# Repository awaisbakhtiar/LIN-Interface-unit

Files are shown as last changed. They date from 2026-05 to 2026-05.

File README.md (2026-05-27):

Developed a LIN Interface Unit for camper van applications to sniff and monitor parameters on the LIN-Bus network. Designed the system to comply with ISO 7637 automotive transient protection standards, incorporating analog and digital isolation, overvoltage and undervoltage protection, and transient suppression circuitry for reliable operation in automotive environments. Integrated an ESP32 for wireless communication with a mobile application over Wi-Fi.

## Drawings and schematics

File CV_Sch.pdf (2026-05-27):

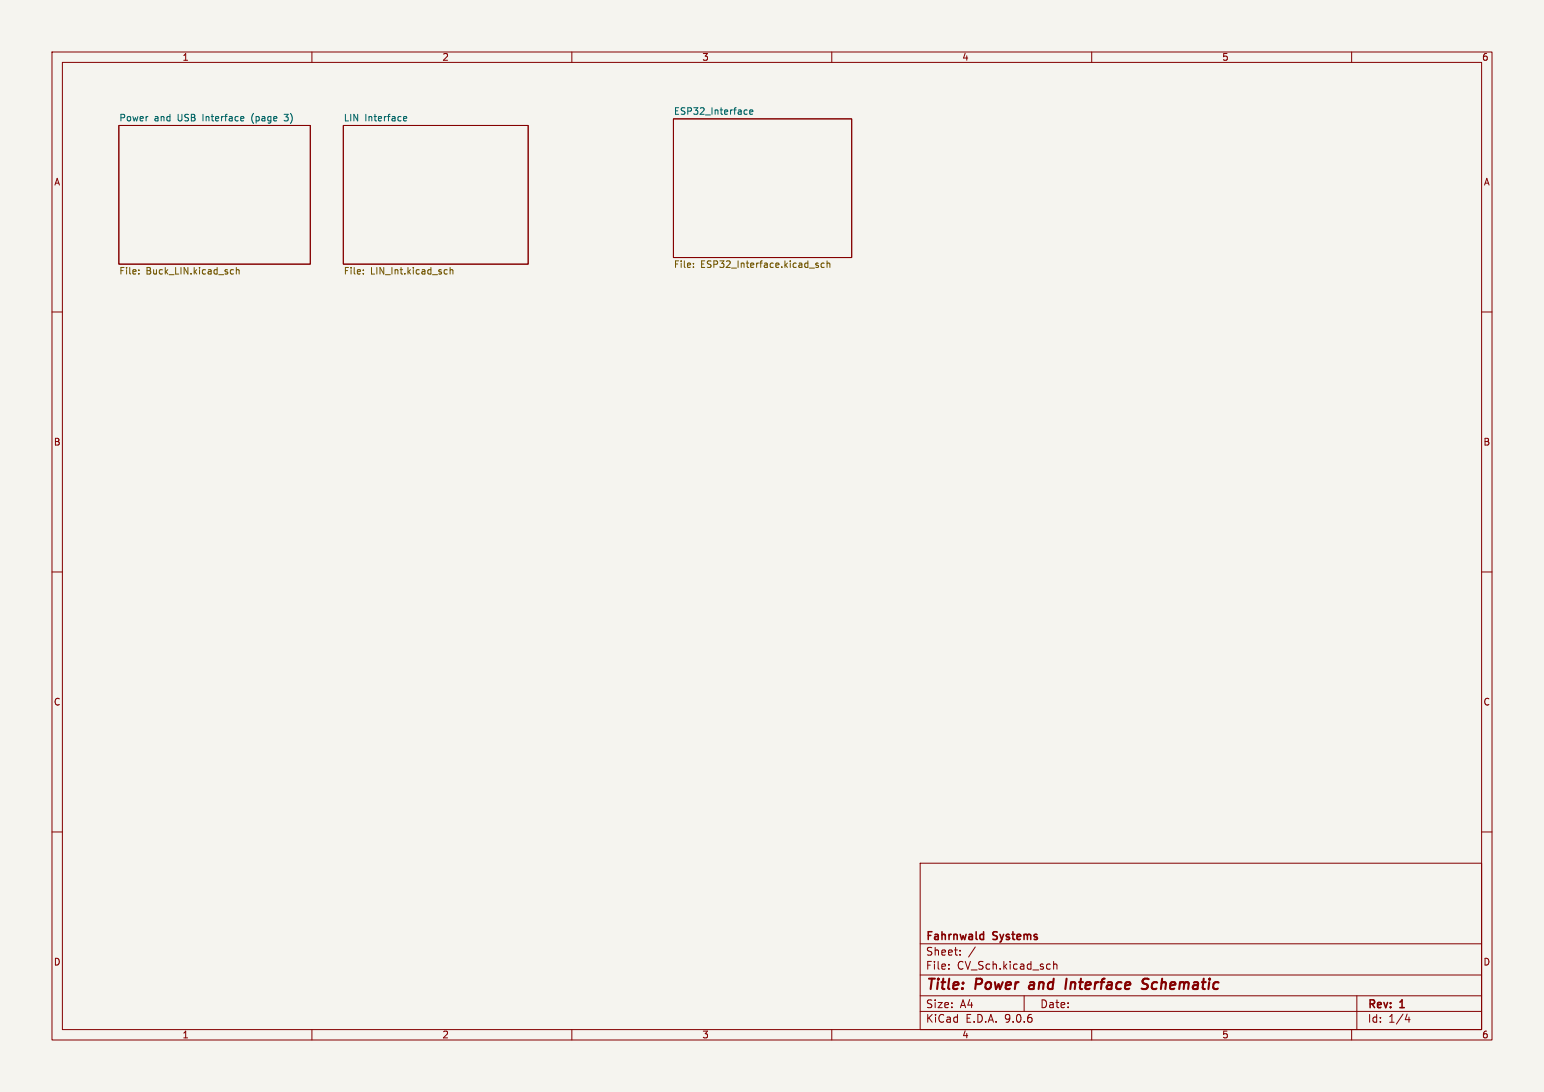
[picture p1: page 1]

Id: 1/4 Title: Power and Interface Schematic

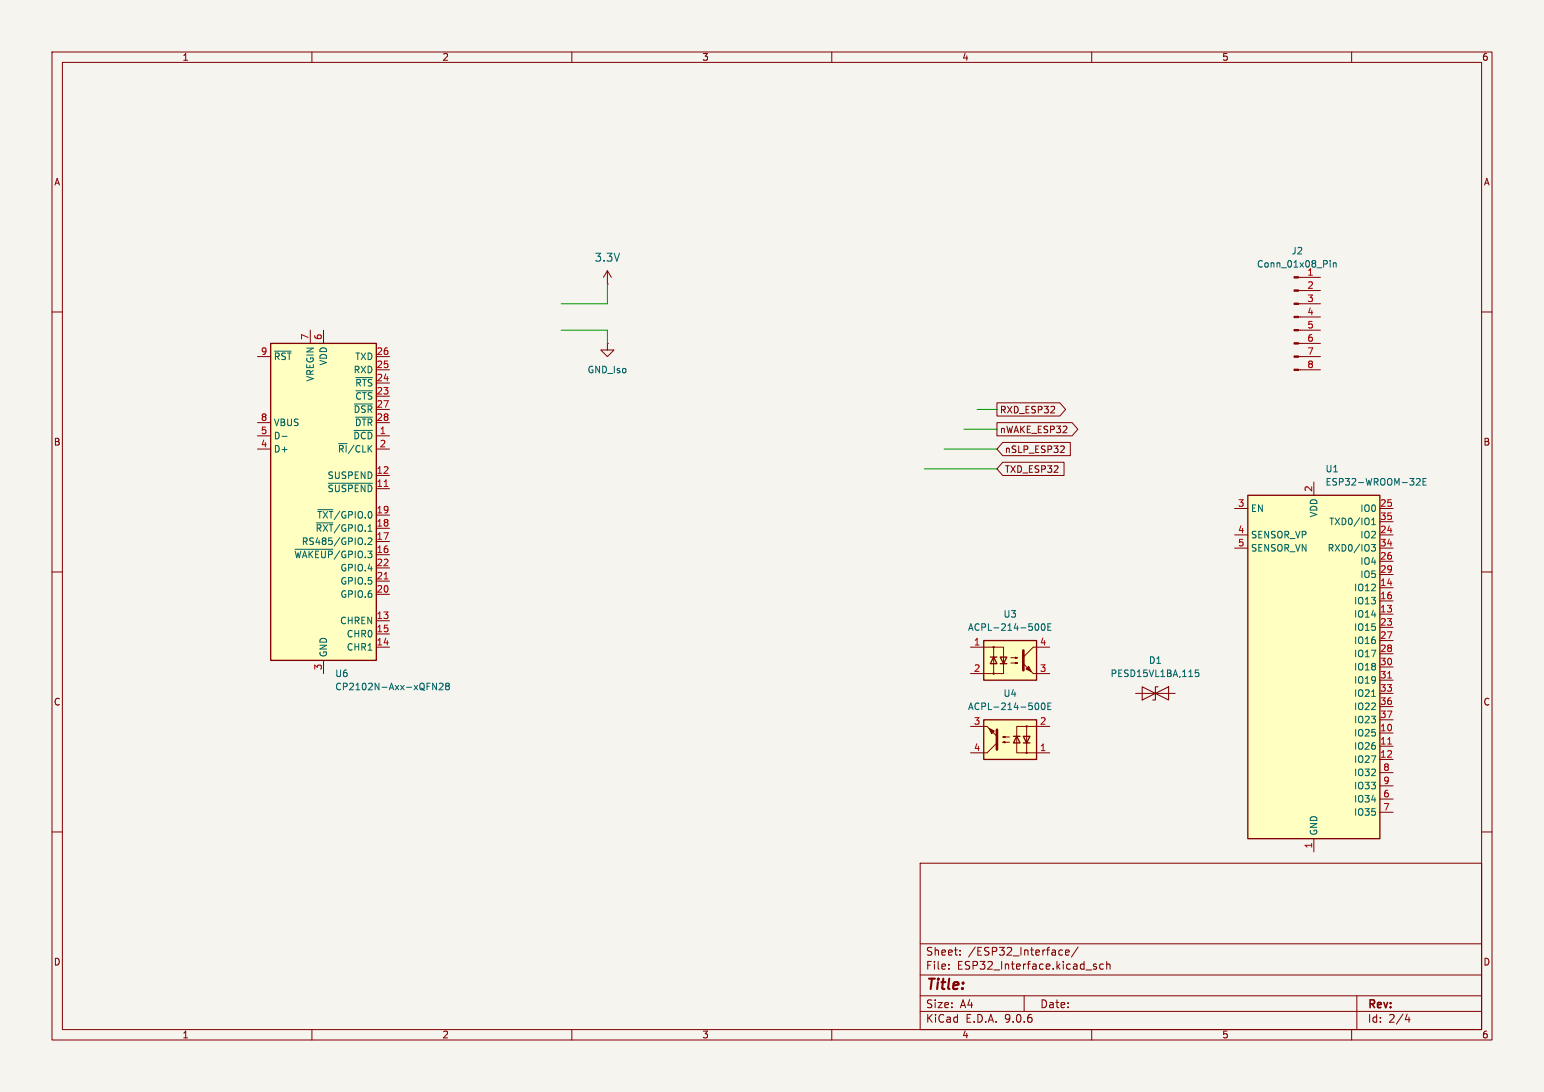
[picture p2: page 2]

Id: 2/4 Title: File: ESP32_Interface.kicad_sch Sheet: /ESP32_Interface/

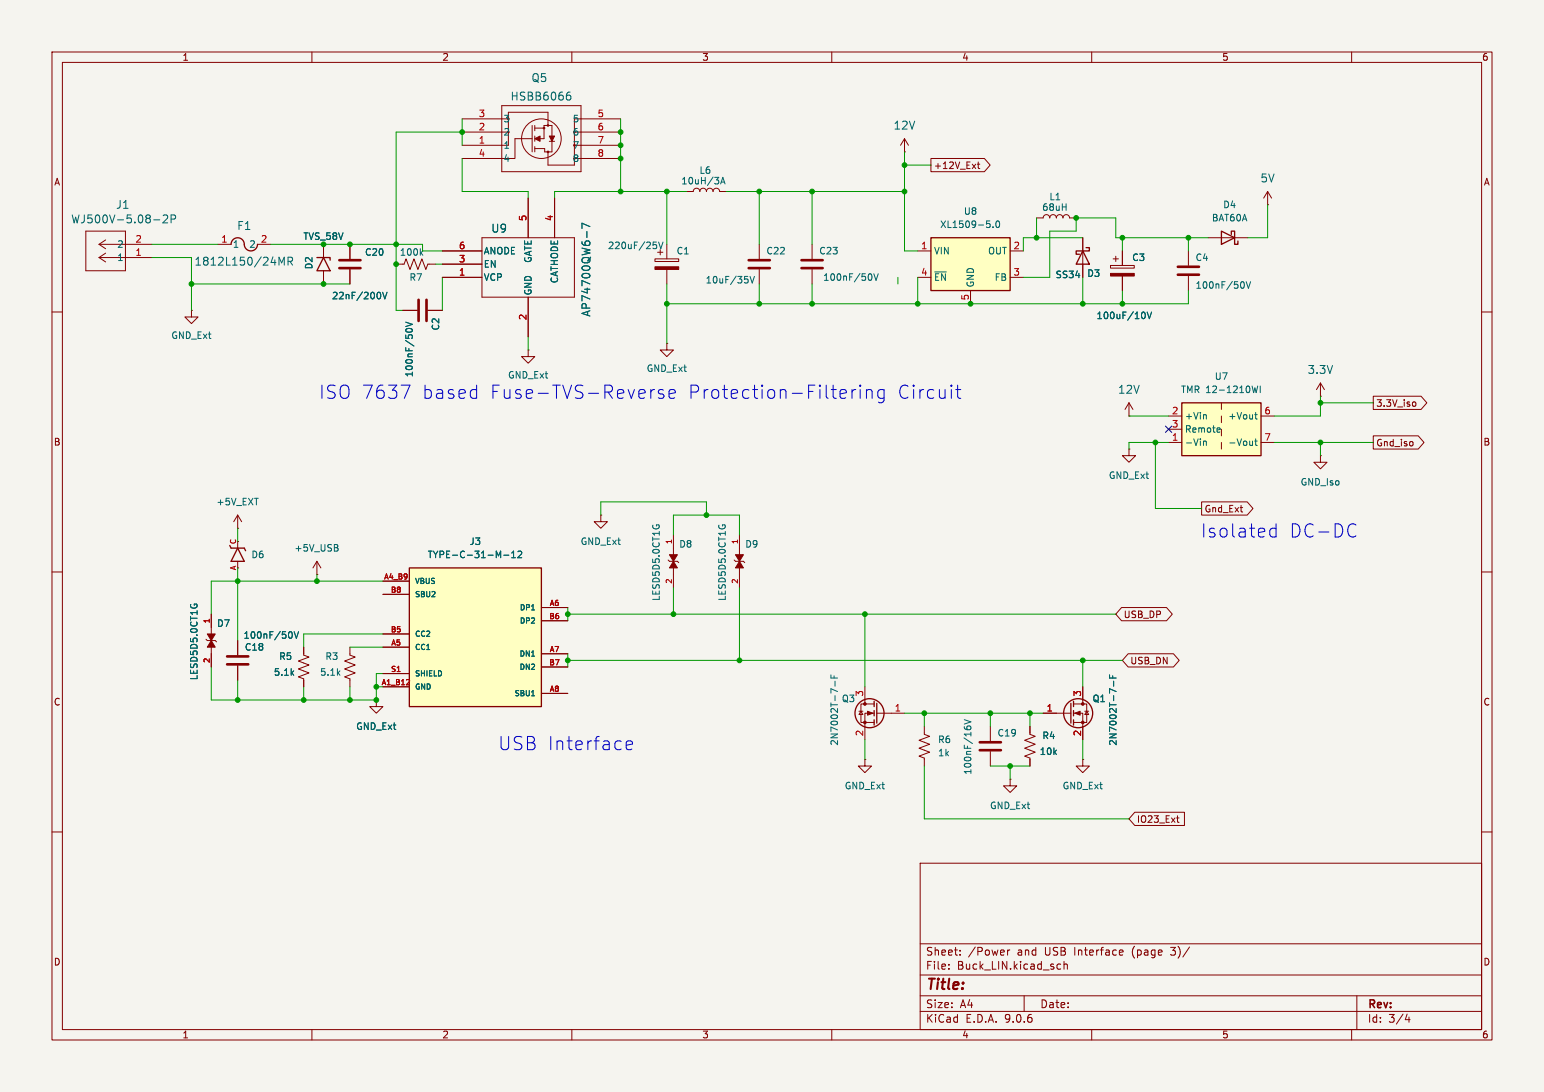
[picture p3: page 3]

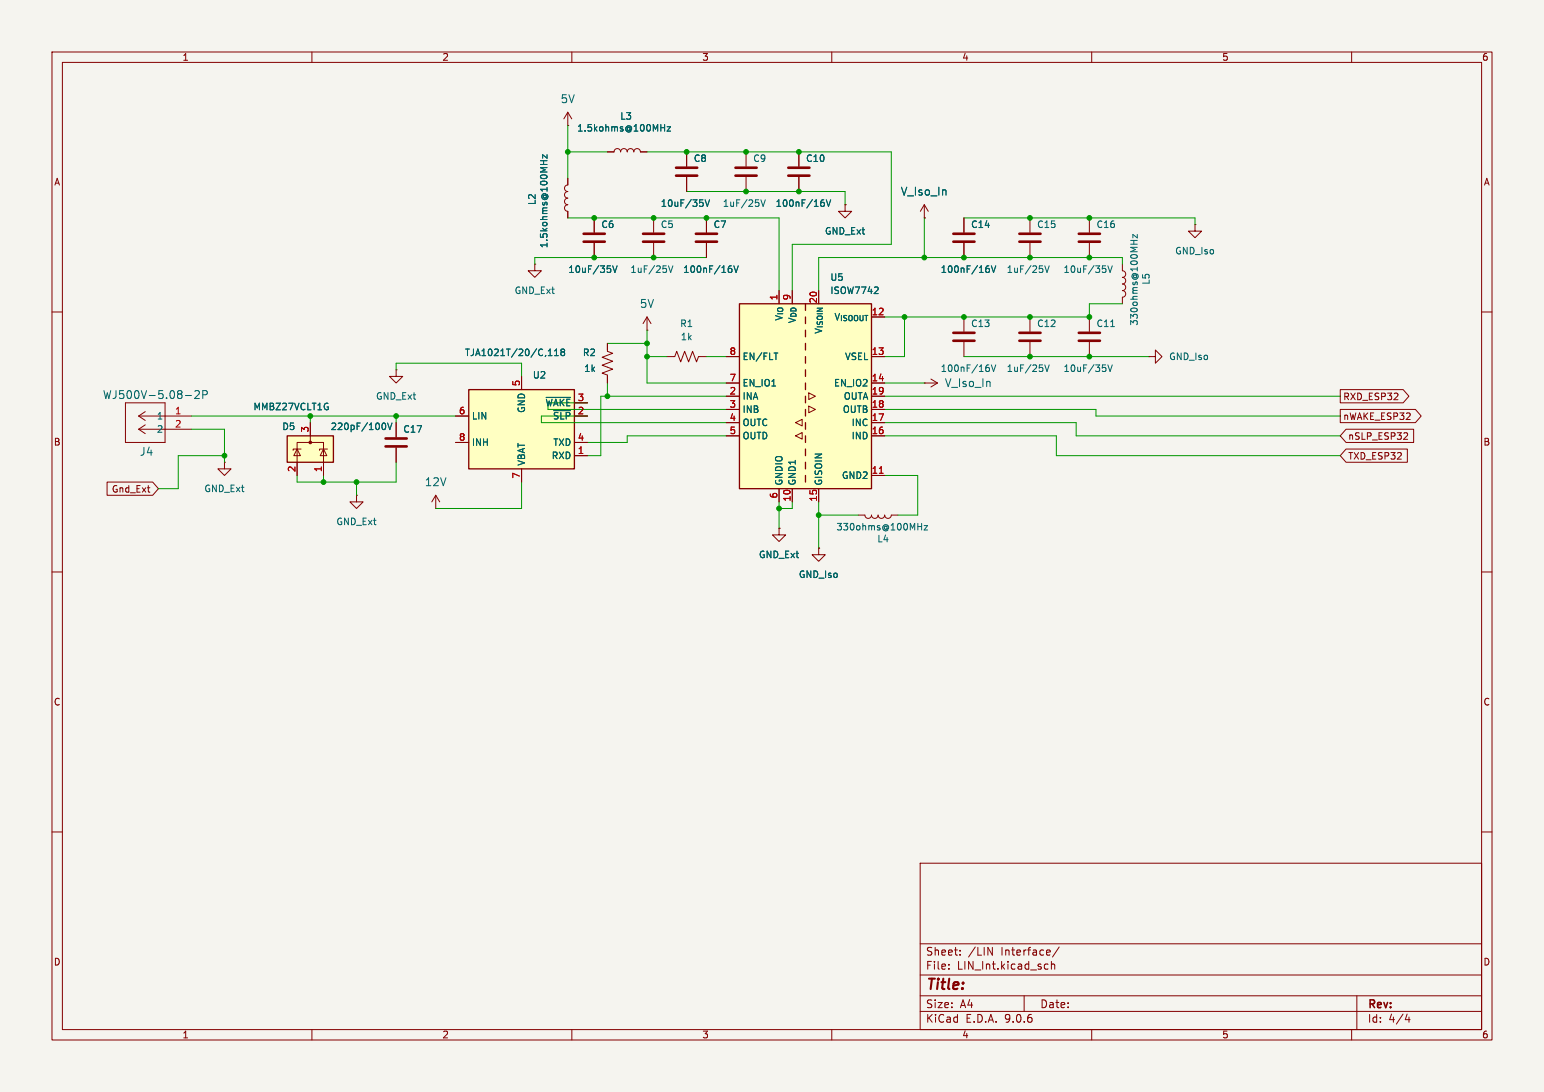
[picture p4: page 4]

1 C17 220pF/100V U2 TJA1021T/20/C,118 RXD 1 TXD 4 ~{SLP}2 ~{WAKE}3 VBAT

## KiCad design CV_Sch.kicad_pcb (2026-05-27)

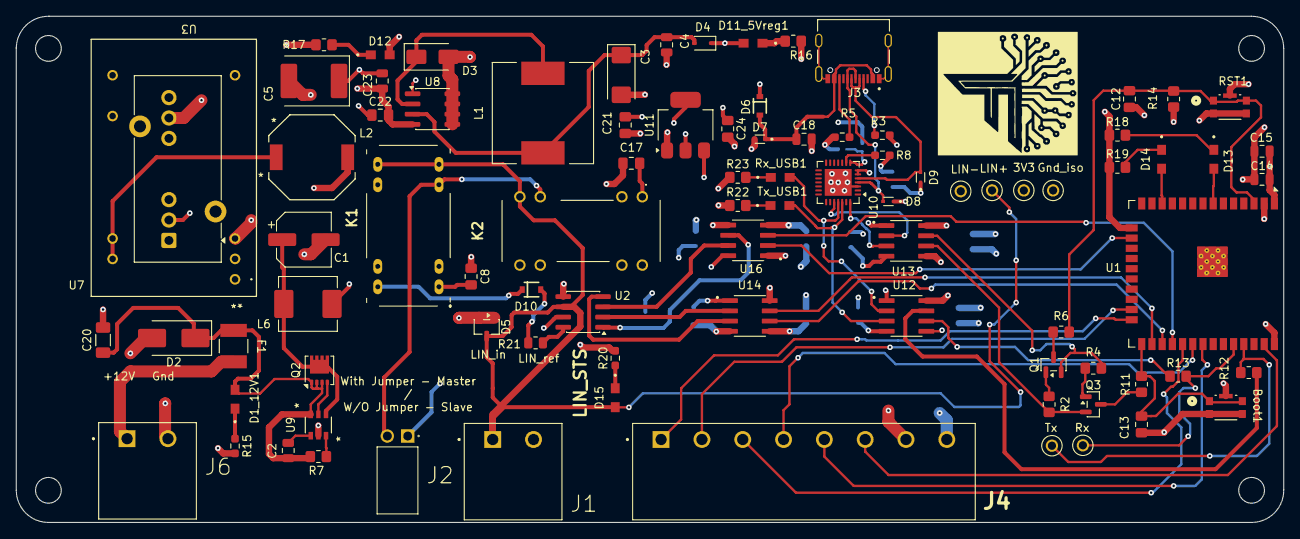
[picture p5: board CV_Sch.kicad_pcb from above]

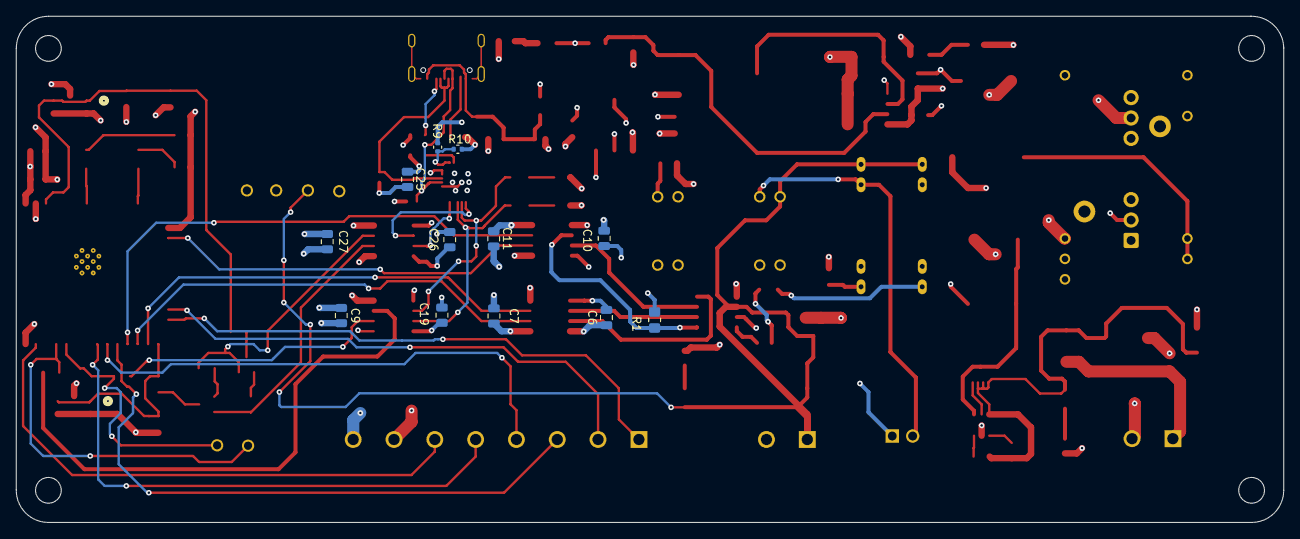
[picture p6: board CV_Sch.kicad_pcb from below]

Board: 4 copper layers, 157.8 x 63.0 mm, 104 parts (12 on the bottom side), 69 nets.

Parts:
Boot1: KMR223G LFG; KMR2_G_CNK_Y78B22310FP
C1: 220uF/25V; CP_Elec_6.3x7.7
C2, C4, C6, C7, C9, C10, C11, C14, C18, C19, C23, C26, C27: 100nF/50V; C_0805_2012Metric
C3: 100uF/10V; CP_EIA-6032-28_Kemet-C
C5: 100uF/25V; CP_EIA-7360-38_Kemet-E
C8: 1nF/50V; C_0805_2012Metric_Pad1.18x1.45mm_HandSolder
C12, C13, C21, C22, C24: 10uF/35V; C_0805_2012Metric_Pad1.18x1.45mm_HandSolder
C15: 22uF/16V; C_0805_2012Metric
C17: 220pF/100V; C_0805_2012Metric_Pad1.18x1.45mm_HandSolder
C20: 22nF/200V; C_1206_3216Metric_Pad1.33x1.80mm_HandSolder
C25: 4.7uF/16V; C_0805_2012Metric
D1_12V1, D11_5Vreg1, D12: APT2012SURCK; LED_APT2012SURCK
D2: TVS_58V; D_SMB_Handsoldering
D3: SS34; D_SMA
D4: BAT60A; D_SOD-323
D5: MMBZ27VCLT1G; SOT-23-3
D6: BAT20JFILM; SOD-323
D7, D8, D9: LESD5D5.0CT1G; TVS_LESD5D5.0CT1G
D10: MBR0520LT1G; SOD-323
D13, D14, D15: APT2012ZGC; LED_APT2012SURCK
F1: 1812L150/24MR; FUSE_1812L150&slash_24_LTF
H1, H2, H3, H4: MountingHole; MountingHole_3.2mm_M3
J1, J6: 1757242; PHOENIX_1757242
J2: M20-9750242; M20-97502XX
J3: TYPE-C-31-M-12; HRO_TYPE-C-31-M-12
J4: 1757307; PHOENIX_1757307
K1: HE722A1210
K2: 8L41-12-001
L1: 68uH; L_12x12mm_H6mm
L2: 12uH; IND_CDRH104_SUM
L6: 10uH/3A; L_TechFuse_SL0624
Q1, Q3: SS8050; SOT-23
Q2: DMT6008LFG; Diodes_PowerDI3333-8
R1, R2, R4, R14: 10k; R_0805_2012Metric_Pad1.20x1.40mm_HandSolder
R3, R5: 5.1k; R_0603_1608Metric_Pad0.98x0.95mm_HandSolder
R6, R11, R12, R13: 22R; R_0805_2012Metric_Pad1.20x1.40mm_HandSolder
R7: 100k; R_0805_2012Metric_Pad1.20x1.40mm_HandSolder
R8, R15, R20: 1k; R_0603_1608Metric_Pad0.98x0.95mm_HandSolder
R9: 22.1k; R_0402_1005Metric
R10: 47.5k; R_0402_1005Metric
R16: 330R; R_0805_2012Metric_Pad1.20x1.40mm_HandSolder
R17, R18, R19, R22, R23: 120R; R_0805_2012Metric_Pad1.20x1.40mm_HandSolder
R21: 1k; R_0805_2012Metric
RST1: KMR223G LFG; KMR2_G_CNK_Y78B22310FP
Rx_USB1: APT2012SURCK; LED_APT2012SURCK
TP1: RH-5000; TestPoint_RH-5001(black)
TP2, TP4: RH-5001; TestPoint_RH-5001(black)
TP3: RH-5004; TestPoint_RH-5001(black)
TP5: RH-5117; TestPoint_RH-5001(black)
TP6: RH-5116; TestPoint_RH-5001(black)
Tx_USB1: APT2012SURCK; LED_APT2012SURCK
U1: ESP32-WROOM-32E; ESP32-WROOM-32D
U2: TJA1021T/20/C,118; SOIC-8_3.9x4.9mm_P1.27mm
U3: JCG1212S3V3; RLA_JCG12_JCG15_SINGLE_XPR
U7: TMR 12-1210WI; Converter_DCDC_TRACO_TMR10-24xxWIR_48xxWIR_72xxWIR_THT
U8: XL1509-5.0; SOIC-8_3.9x4.9mm_P1.27mm
U9: AP74700QW6-7; SOT26_DIO
U10: CP2102N-A02-GQFN28R; QFN-28-1EP_5x5mm_P0.5mm_EP3.35x3.35mm
U11: AMS1117-3.3; SOT-223-3_TabPin2
U12: ISO7421DR; SOIC127P599X175-8N
U13, U14, U16: ISO7420FED; SOIC127P599X175-8N

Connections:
3.3V_iso: C7.2, C9.2, C11.2, C14.1, C15.2, C27.2, D12.2, J4.07, R14.1, TP1.TP, U1.2 (VDD), U3.14 (+VOUT), U7.6 (+Vout), U12.8 (VCC2), U13.8 (VCC2), U14.8 (VCC2), U16.1 (VCC1)
5V_Ext: C6.1, C10.1, C21.1, D4.1 (K), D6.C, D11_5Vreg1.2, R1.2, R9.2, U11.3 (VI), U14.1 (VCC1), U16.8 (VCC2)
+3.3V_EXT: C19.2, C24.1, C25.1, C26.1, R8.2, U10.6 (VDD), U10.7 (VREGIN), U11.2 (VO), U12.1 (VCC1), U13.1 (VCC1)
+5V_USB: C18.1, D6.A, D7.1, J3.A4_B9 (VBUS), J3.B4_A9 (VBUS)
+12V_Ext: C5.1, C22.1, C23.1, J2.1, L2.2, L6.2, U2.7 (VBAT), U7.2 (+Vin), U8.1 (VIN)
/ESP32_Interface/EN: C12.2, R6.2, R14.2, RST1.1, RST1.2, U1.3 (EN)
/ESP32_Interface/GPIO_1_Ext: J4.01, U1.24 (IO2)
/ESP32_Interface/GPIO_2_Ext: J4.02, U1.23 (IO15)
/ESP32_Interface/IO0: Boot1.1, Boot1.2, C13.2, R11.1, U1.25 (IO0)
/ESP32_Interface/MISO: J4.05, U1.31 (IO19)
/ESP32_Interface/MOSI: J4.06, U1.37 (IO23)
/ESP32_Interface/RXD0: R13.2, TP6.TP, U1.34 (RXD0/IO3)
/ESP32_Interface/SCLK: J4.04, U1.30 (IO18)
/ESP32_Interface/SPI_CS: J4.03, U1.29 (IO5)
/ESP32_Interface/TXD0: R12.2, TP5.TP, U1.35 (TXD0/IO1)
/LIN Interface/LIN_Input: D5.3 (A), D15.2, J1.01, K1.7 (COM_1), K1.8 (COM_2), K2.7 (COM_1), TP3.TP, U2.6 (LIN)
/Power and USB Interface (page 3)/RX_CP: Rx_USB1.2, U10.25 (RXD), U12.2 (OUTA)
/Power and USB Interface (page 3)/TX_CP: Tx_USB1.2, U10.26 (TXD), U12.3 (INB)
Gnd_Ext: C1.2, C3.2, C4.2, C5.2, C6.2, C8.2, C10.2, C17.2, C18.2, C19.1, C20.2, C21.2, C22.2, C23.2, C24.2, C25.2, C26.2, D2.2 (A2), D3.2 (A), D5.1 (K), D5.2 (K), D7.2, D8.1, D9.1, J1.02, J3.A1_B12 (GND), J3.B1_A12 (GND), J3.S1 (SHIELD), J3.S2 (SHIELD), J3.S3 (SHIELD), J3.S4 (SHIELD), J6.02, K1.2 (COIL+), K2.2 (COIL_1), R3.1, R5.1, R10.2, R15.1, R16.1, R20.1, R22.1, R23.1, TP4.TP, U2.5 (GND), U3.2 (-VIN), U3.3 (-VIN), U7.1 (-Vin), U8.4 (~EN), U8.5 (GND), U8.6 (GND), U8.7 (GND), U8.8 (GND), U9.2 (GND), U10.3 (GND), U10.29 (GND), U11.1 (GND), U12.4 (GND1), U13.4 (GND1), U14.4 (GND1), U16.5 (GND2)
Gnd_iso: Boot1.3, Boot1.4, Boot1.5, C7.1, C9.1, C11.1, C12.1, C13.1, C14.2, C15.1, C27.1, J4.08, R17.1, R18.1, R19.1, RST1.3, RST1.4, RST1.5, TP2.TP, U1.1 (GND), U1.15 (GND), U1.38 (GND), U1.39 (GND), U3.16 (-VOUT), U7.7 (-Vout), U12.5 (GND2), U13.5 (GND2), U14.5 (GND2), U16.4 (GND1)
unnamed: D1_12V1.1, R15.2
unnamed: C2.2, C20.1, D1_12V1.2, D2.1 (A1), F1.2, Q2.1 (S), Q2.2 (S), Q2.3 (S), R7.2, U9.6 (ANODE)
unnamed: D3.1 (K), L1.1, U8.2 (OUT)
unnamed: C3.1, C4.1, D4.2 (A), L1.2, U8.3 (FB)
unnamed: D10.A, R21.1
unnamed: D11_5Vreg1.1, R16.2
unnamed: D12.1, R17.2
unnamed: D13.1, R18.2
unnamed: D14.1, R19.2
unnamed: D15.1, R20.2
unnamed: F1.1, J6.01
unnamed: J3.A5 (CC1), R3.2
unnamed: J3.B5 (CC2), R5.2
unnamed: D9.2, J3.A7 (DN1), J3.B7 (DN2), U10.5 (D-)
unnamed: D8.2, J3.A6 (DP1), J3.B6 (DP2), U10.4 (D+)
unnamed: J2.2, K1.6 (COIL-), K2.6 (COIL_2)
unnamed: C8.1, K1.1 (NO_1)
unnamed: D10.C, K1.14 (NO_2)
unnamed: C17.1, K2.1 (NC)
unnamed: L2.1, U3.22 (+VIN), U3.23 (+VIN)
unnamed: Q1.1 (B), R2.1
unnamed: Q1.3 (C), R6.1
unnamed: C1.1, L6.1, Q2.5 (D), U9.4 (CATHODE)
unnamed: Q2.4 (G), U9.5 (GATE)
unnamed: Q3.1 (B), R4.1
unnamed: Q3.3 (C), R11.2
unnamed: R22.2, Tx_USB1.1
unnamed: R23.2, Rx_USB1.1
unnamed: D14.2, U1.12 (IO27)
unnamed: D13.2, U1.7 (IO35)
unnamed: R21.2, U2.8 (INH)
unnamed: R7.1, U9.3 (EN)
unnamed: C2.1, U9.1 (VCP)
unnamed: R9.1, R10.1, U10.8 (VBUS)
unnamed: U10.28 (~DTR), U13.3 (INB)
unnamed: R8.1, U10.9 (~RST)
unnamed: U10.24 (~RTS), U13.2 (INA)
unnamed: U2.2 (~SLP), U14.2 (INA)
unnamed: U2.4 (TXD), U14.3 (INB)
unnamed: U2.3 (~WAKE), U16.7 (OUTA)
unnamed: R1.1, U2.1 (RXD), U16.6 (OUTB)
RxD_ESP32: R13.1, U12.6 (OUTB)
RxLIN_ESP32: U1.27 (IO16), U14.6 (OUTB)
TxD_ESP32: R12.1, U12.7 (INA)
TxLIN_ESP32: U1.28 (IO17), U16.3 (INB)
nDTR_ESP32: Q3.2 (E), R2.2, U13.6 (OUTB)
nRTS_ESP32: Q1.2 (E), R4.2, U13.7 (OUTA)
nSLP_ESP32: U1.26 (IO4), U14.7 (OUTA)
nWAKE_ESP32: U1.16 (IO13), U16.2 (INA)
